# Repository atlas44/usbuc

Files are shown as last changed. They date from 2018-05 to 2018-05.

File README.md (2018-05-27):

# usbuc
A PIC32 based modchip for the Nintendo Switch.

## Description
This is an experimental WIP modchip designed to fit inside of the Switch that will trigger [Fusee Gelee](https://github.com/reswitched/fusee-launcher) automatically on boot to launch an arbitrary payload. Installing it requires soldering 5 wires.

## Pictures
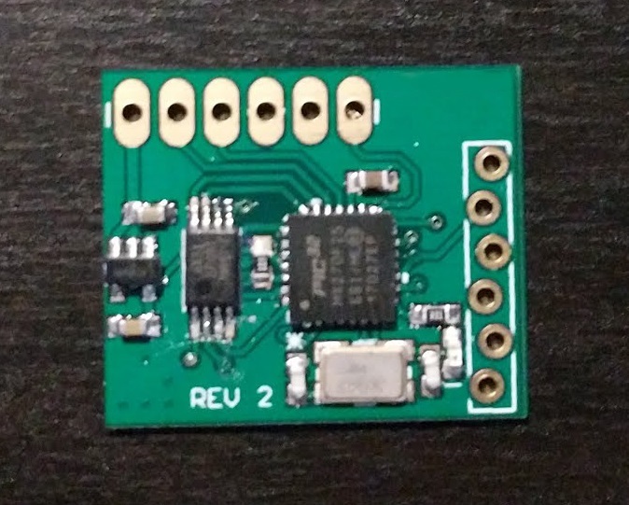
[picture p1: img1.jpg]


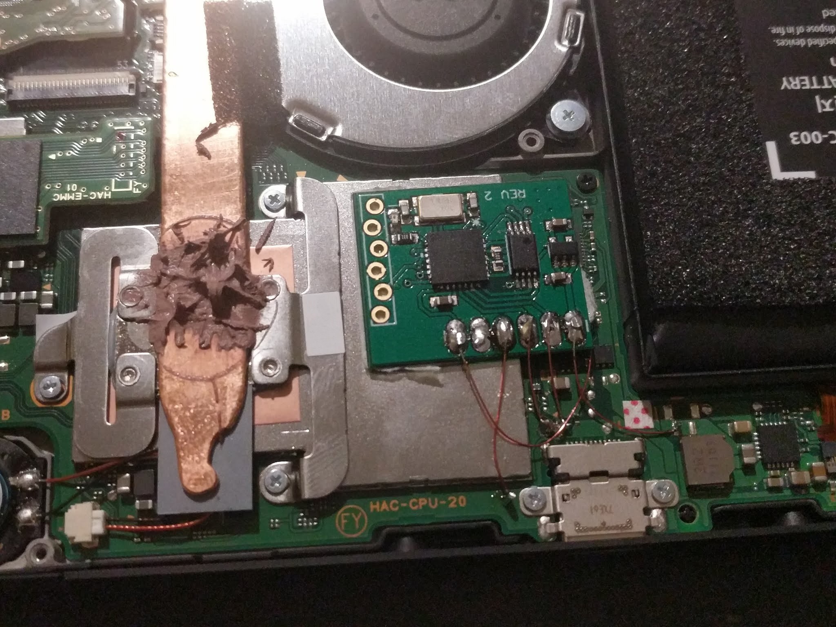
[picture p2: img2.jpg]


## Disclaimer
This is a work-in-process, extremely experimental, and has only had limited testing! If you are not comfortable with small soldering and both software and hardware debugging you should not use this! Mistakes can easily result in a permanently damaged Switch!

## Installation Instructions
TODO

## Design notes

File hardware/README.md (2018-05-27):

# Hardware

## Parts List

### Somewhat Specific parts
| Quantity | Part  | Description | Cost for 1 | Link
| --- | ----- | --- | --- | ----
| 1 | PIC32MX270F256B-I/ML | Microcontroller | $3.99 | [DigiKey](https://www.digikey.com/product-detail/en/microchip-technology/PIC32MX270F256B-I-ML/PIC32MX270F256B-I-ML-ND/4902628)
| 1 | NCP551SN | Voltage Regulator | $0.57 | [DigiKey](https://www.digikey.com/product-detail/en/on-semiconductor/NCP551SN33T1G/NCP551SN33T1GOSCT-ND)
| 1 | AT25SF081-XMHD-T | Flash Storage (OPTIONAL! Gives extra space for more payloads) | $0.71 | [DigiKey](https://www.digikey.com/product-detail/en/adesto-technologies/AT25SF081-XMHD-T/1265-1277-1-ND/6827525)

### Easily Substitutable parts
| Quantity | Part  | Description | Cost for 1 | Link
| --- | ----- | --- | --- | ----
| 1 | 8.000 MHz Crystal, 5x3.2 | Crystal Oscillator | $0.69 | [DigiKey](https://www.digikey.com/product-detail/en/abracon-llc/ABM3B-8.000MHZ-10-1-U-T/535-9721-1-ND/1873255)
| 2 | 18pF Capacitor 0603 | Capacitors for crystal | $0.10 | [DigiKey](https://www.digikey.com/product-detail/en/yageo/CC0603GRNPO9BN180/311-3922-1-ND/8025011)
| 2 | 1uF Capacitor 0603 | Decoupling capacitors | $0.10 | [DigiKey](https://www.digikey.com/product-detail/en/samsung-electro-mechanics/CL10A105KQ8NNNC/1276-1036-1-ND/3889122)
| 1 | 10uF Capacitor 0603 | Capacitor for microcontroller's internal regulator | $0.21 | [DigiKey](https://www.digikey.com/product-detail/en/tdk-corporation/C1608X5R0J106M080AB/445-4112-1-ND/1975462)
| 1 | 10K Resistor 0603 | Reset pull-up | $0.10 | [DigiKey](https://www.digikey.com/product-detail/en/stackpole-electronics-inc/RMCF0603JG10K0/RMCF0603JG10K0CT-ND/4425128)
| 1 | Green LED 0603 | Indicator LED (OPTIONAL) | $0.27 | [DigiKey](https://www.digikey.com/product-detail/en/lite-on-inc/LTST-S270KGKT/160-1478-1-ND/386892)
| 1 | 330 Resistor 0603 | Resistor for LED (OPTIONAL) | $0.10 | [DigiKey](https://www.digikey.com/product-detail/en/stackpole-electronics-inc/RMCF0603JT330R/RMCF0603JT330RCT-ND/1943164)

Cost per unit with all optional parts, excluding PCB, @1: $7.04

Cost per unit with all optional parts, excluding PCB, @100: $5.6213

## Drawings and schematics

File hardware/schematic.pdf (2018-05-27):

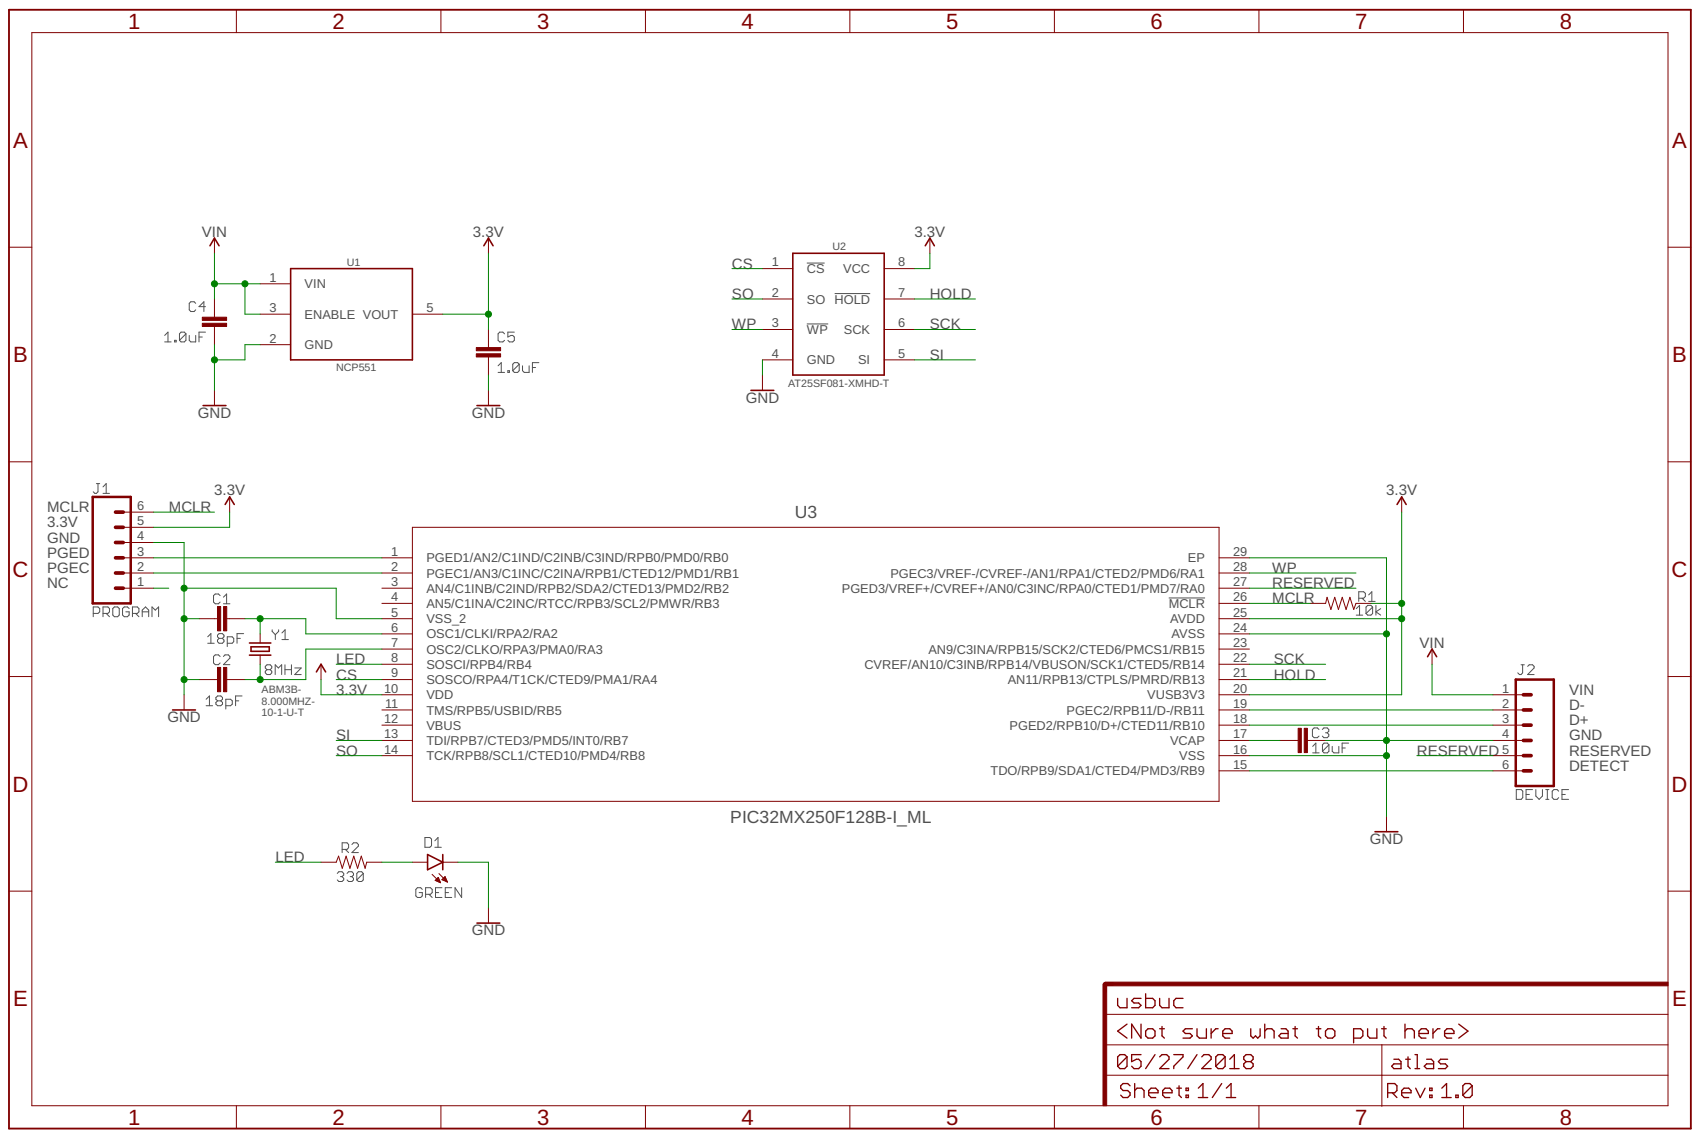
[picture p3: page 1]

18 PGEC2/RPB11/D-/RB11 | 3

17 PGED2/RPB10/D+/CTED11/RB10 | | 4

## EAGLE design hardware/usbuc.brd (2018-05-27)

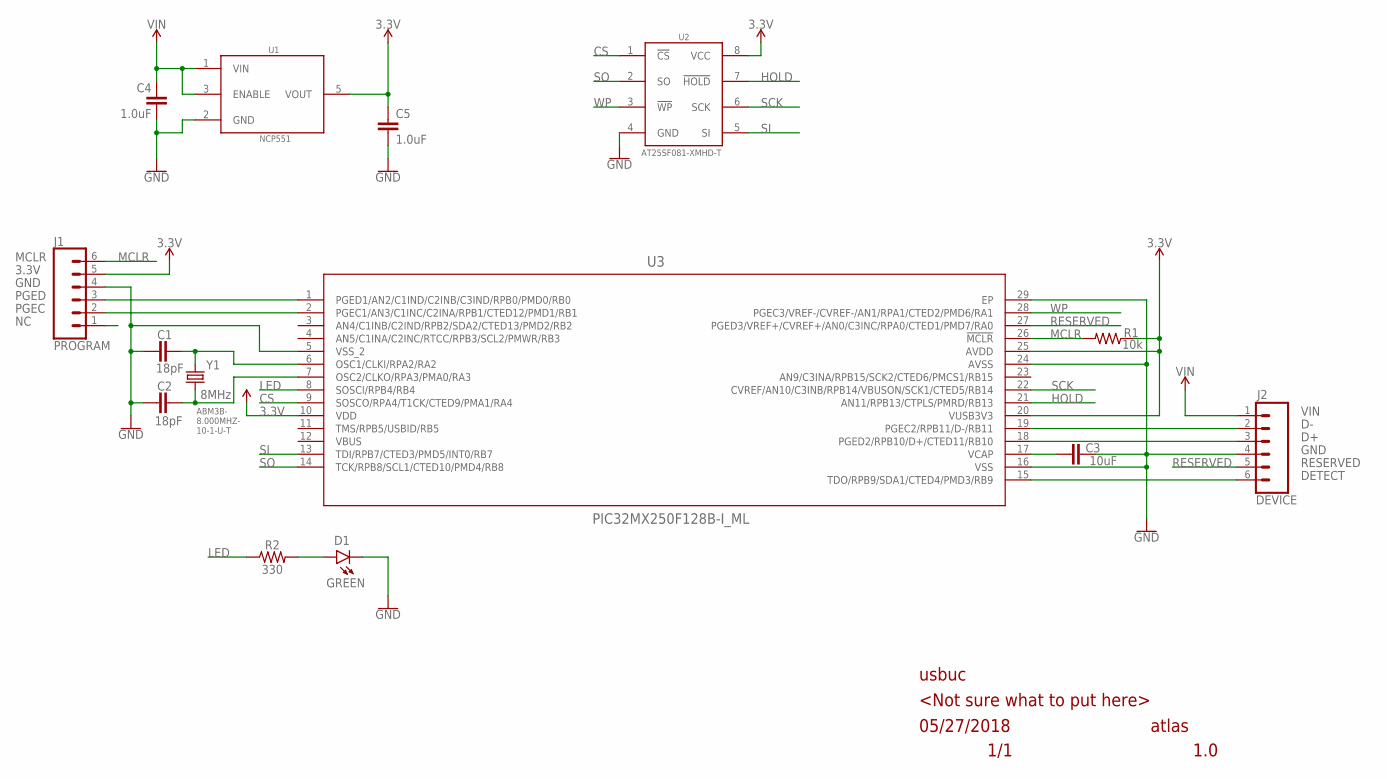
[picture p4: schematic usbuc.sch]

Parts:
C1, C2: 18pF; 0603
C3: 10uF; 0603
C4, C5: 1.0uF; 0603
D1: GREEN; LED-0603
J1: PROGRAM; 1X06_FEMALE_LOCK.010
J2: DEVICE; 1X06_LONGPADS
R1: 10k; 0603
R2: 330; 0603
U1: NCP551; TSOP-5
U2: AT25SF081-XMHD-T; TSSOP8
U3: PIC32MX250F128B-I_ML; QFN28_6X6MC
Y1: 8MHz; CRYSTAL-SMD-5X3.2-4PAD

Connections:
3.3V: C5.1, J1.5, R1.1, U1.5 (VOUT), U2.8 (VCC), U3.10 (VDD), U3.20 (VUSB3V3), U3.25 (AVDD)
CS: U2.1 (!CS), U3.9 (SOSCO/RPA4/T1CK/CTED9/PMA1/RA4)
D+: J2.3, U3.18 (PGED2/RPB10/D+/CTED11/RB10)
D-: J2.2, U3.19 (PGEC2/RPB11/D-/RB11)
DETECT: J2.6, U3.15 (TDO/RPB9/SDA1/CTED4/PMD3/RB9)
GND: C1.1, C2.1, C3.2, C4.2, C5.2, D1.C, J1.4, J2.4, U1.2 (GND), U2.4 (GND), U3.5 (VSS_2), U3.16 (VSS), U3.24 (AVSS), U3.29 (EP)
HOLD: U2.7 (!HOLD), U3.21 (AN11/RPB13/CTPLS/PMRD/RB13)
LED: R2.1, U3.8 (SOSCI/RPB4/RB4)
MCLR: J1.6, R1.2, U3.26 (!MCLR)
unnamed: D1.A, R2.2
unnamed: C1.2, U3.6 (OSC1/CLKI/RPA2/RA2), Y1.3 (2)
unnamed: C2.2, U3.7 (OSC2/CLKO/RPA3/PMA0/RA3), Y1.1
unnamed: C3.1, U3.17 (VCAP)
NC: J1.1
PGEC: J1.2, U3.2 (PGEC1/AN3/C1INC/C2INA/RPB1/CTED12/PMD1/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)
PGED: J1.3, U3.1 (PGED1/AN2/C1IND/C2INB/C3IND/RPB0/PMD0/R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)
RESERVED: J2.5, U3.27 (PGED3/VREF+/CVREF+/AN0/C3INC/RPA0/CTED1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)
SCK: U2.6 (SCK), U3.22 (CVREF/AN10/C3INB/RPB14/VBUSON/SCK1/CTED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)
SI: U2.5 (SI), U3.13 (TDI/RPB7/CTED3/PMD5/INT0/RB7)
SO: U2.2 (SO), U3.14 (TCK/RPB8/SCL1/CTED10/PMD4/RB8)
VBUS: U3.12 (VBUS)
VIN: C4.1, J2.1, U1.1 (VIN), U1.3 (ENABLE)
WP: U2.3 (!WP), U3.28 (PGEC3/VREF-/CVREF-/AN1/RPA1/CTED2/PMD6/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)

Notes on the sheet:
usbuc
<Not sure what to put here>
05/27/2018
atlas
1/1
1.0
ABM3B- 8.000MHZ- 10-1-U-T

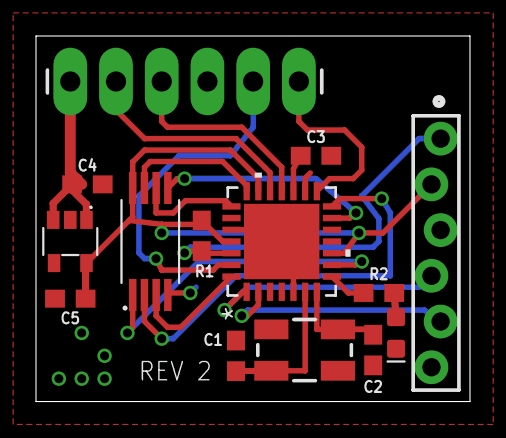
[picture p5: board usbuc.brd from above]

Board: 2 copper layers, 24.1 x 20.3 mm, 15 parts (0 on the bottom side), 21 nets.

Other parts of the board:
FRAME1: FRAME-A4L; DUMMY

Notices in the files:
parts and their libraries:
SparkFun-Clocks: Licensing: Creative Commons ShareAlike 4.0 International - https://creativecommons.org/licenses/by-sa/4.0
